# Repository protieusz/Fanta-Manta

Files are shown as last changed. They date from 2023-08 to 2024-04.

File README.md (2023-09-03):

# Fanta-Manta

Resurrection of the Manta closed source pcb by rainkeebs using Waveshare RP2040 zero.
Generously sponsored by jcastaneda from MechWild discord.

I did the design as closely to the originaly rainkeebs design as much as possible with the difference of using a RP2040 instead of Pro Micro.
This design resurrection was blessed by rainkeebs himself.
PCBs are currently in production. 1 Aug 2023.

Print the designs at your own risk.  No support is given. Thanks.

I accept any tips or donations of a cup of coffee to help keep me motivate but you don't have to if you don't want to. Thanks. https://ko-fi.com/protieusz
Update: 18 Aug 2023

Final Product Build






Unboxing


Front


Back


Test Fitting























PCB model

Front side




Bottom side. Fanta-Manta logo by jcastaneda


This logo is from https://logowik.com/fanta-new-vector-logo-3767.html


Case








Meme Add Case 3 Aug 2023










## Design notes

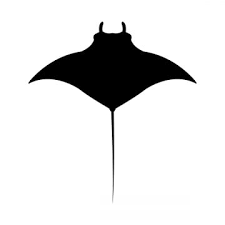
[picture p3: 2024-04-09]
STLs/Manta shape/Manta.png

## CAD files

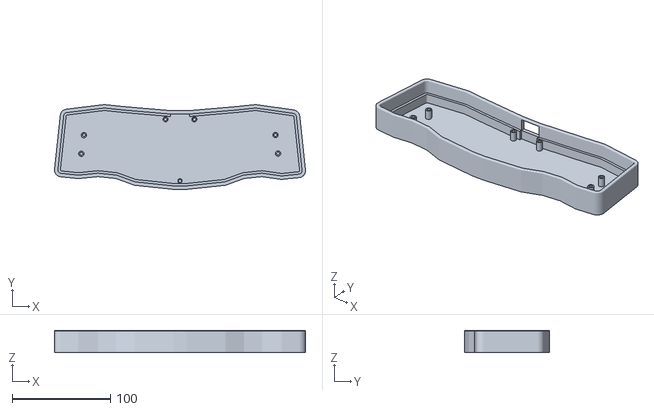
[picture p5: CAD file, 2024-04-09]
STLs/FullCase/FANTA MANTA FullCase.stl
255.0 x 86.1 x 22.8

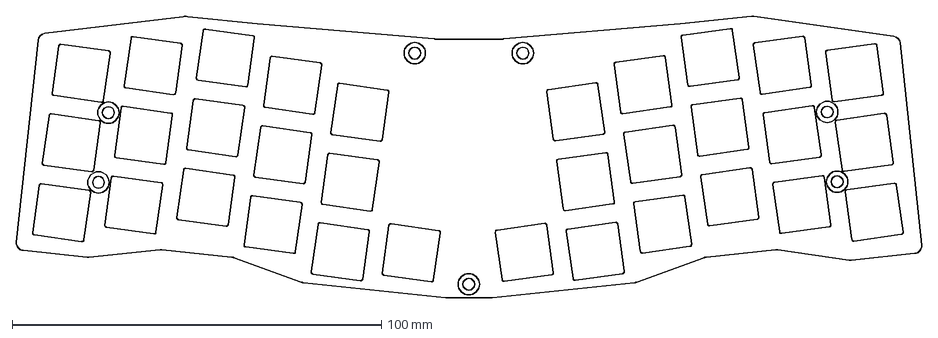
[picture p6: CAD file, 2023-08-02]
Correct Scale Fanta/FantaCorrectDxf.dxf
245.1 x 76.2 mm

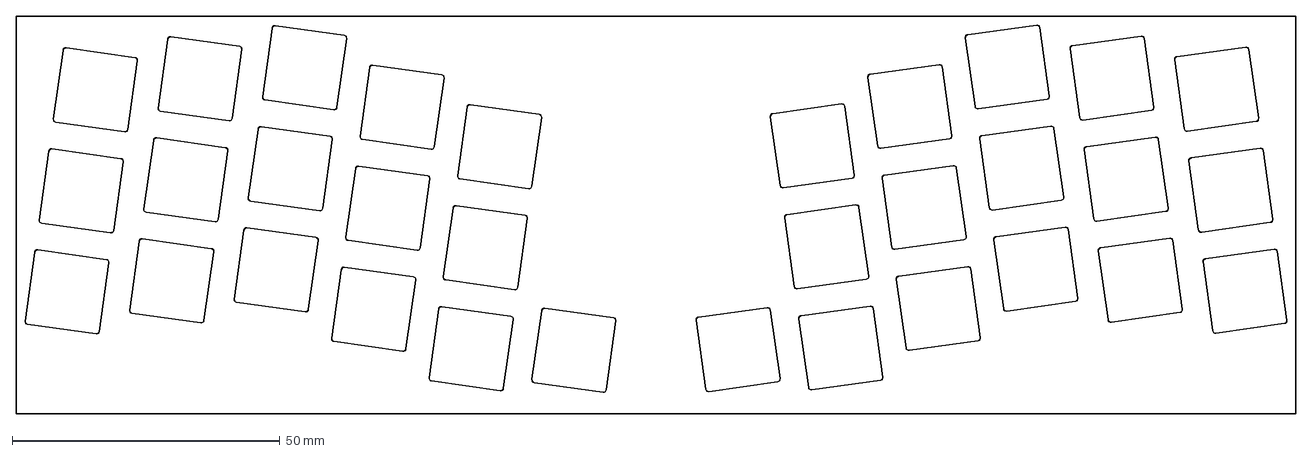
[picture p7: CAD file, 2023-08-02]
KLE layout/FantaKeylayout.dxf
239.0 x 74.3 mm

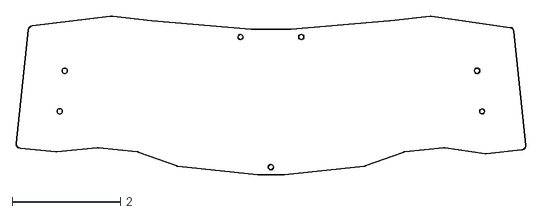
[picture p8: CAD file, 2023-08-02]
OriginNotToScalebottomplate/bottom_plate-Edge_Cuts.dxf
9.43 x 2.93

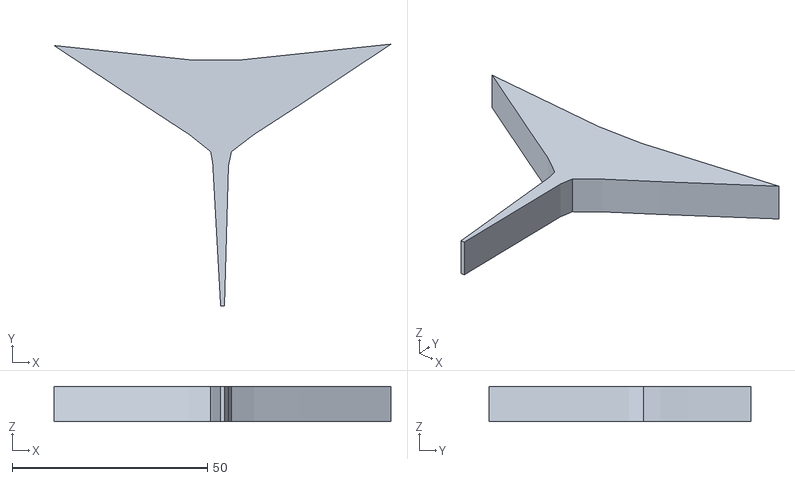
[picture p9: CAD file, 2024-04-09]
STLs/FANTA MANTATail.stl
86.3 x 67.1 x 9.00

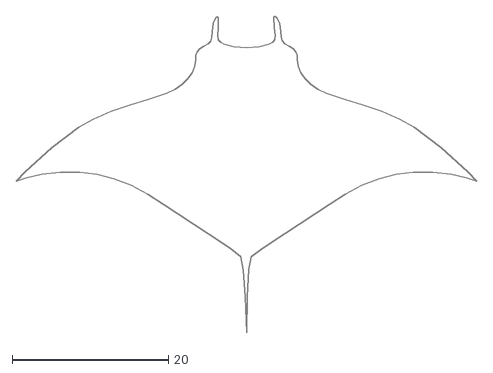
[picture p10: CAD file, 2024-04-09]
STLs/Manta shape/FabConvert.com_manta.dxf
59.0 x 40.5

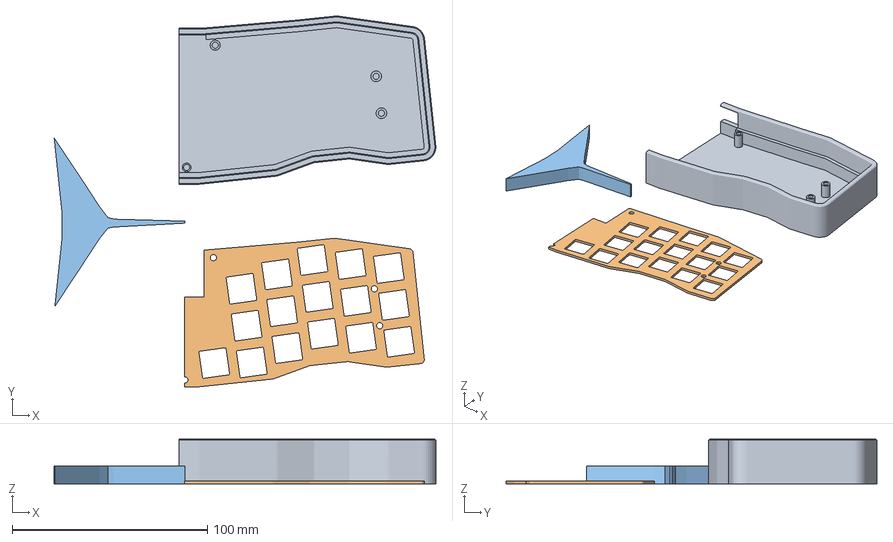
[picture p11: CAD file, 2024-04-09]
STLs/RPL/UM2_FANTA MANTACaseSWRIGHTTail.3mf
195.4 x 189.9 x 22.8 mm
FANTA MANTACaseRIGHT.stl
FANTA MANTASwitchRIGHT.stl
FANTA MANTATail.stl

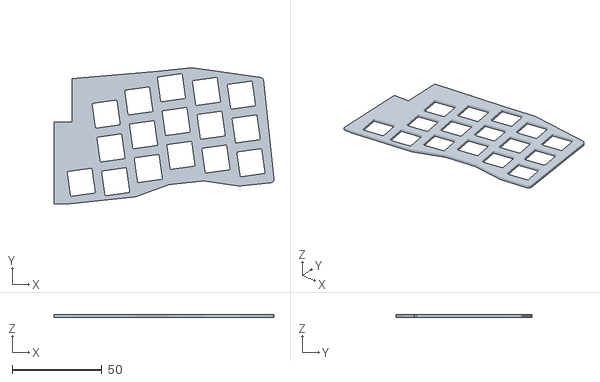
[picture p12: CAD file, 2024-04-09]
STLs/SplitCase/FANTA MANTASwitchRIGHT.stl
122.7 x 76.1 x 1.50

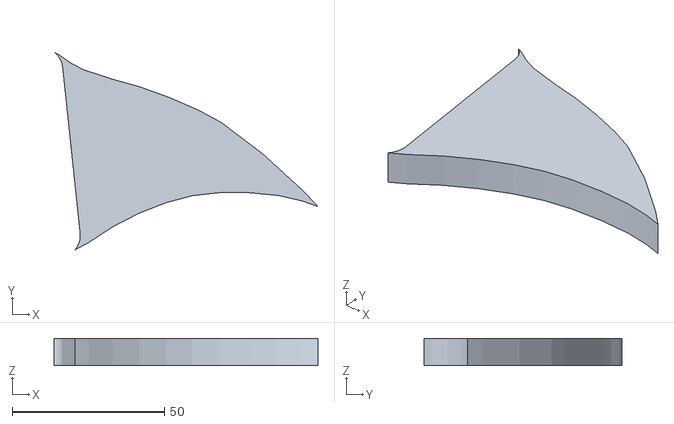
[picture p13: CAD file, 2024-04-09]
STLs/FANTA MANTARIGHTWing.stl
86.8 x 65.1 x 9.00

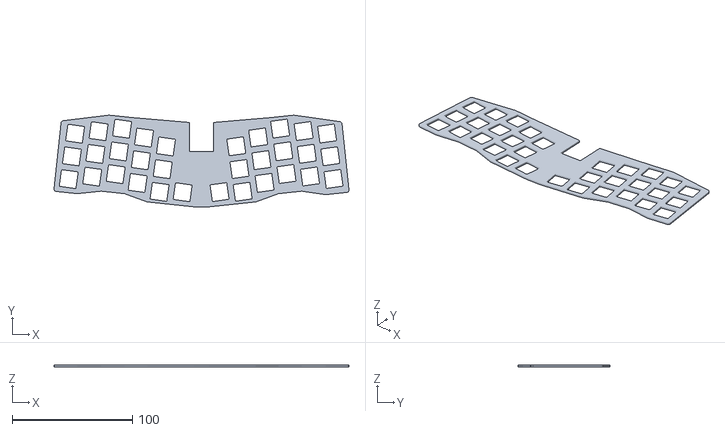
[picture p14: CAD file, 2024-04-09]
STLs/FullCase/FANTA MANTA SwitchPlateNoHoles.stl
245.0 x 76.1 x 1.50

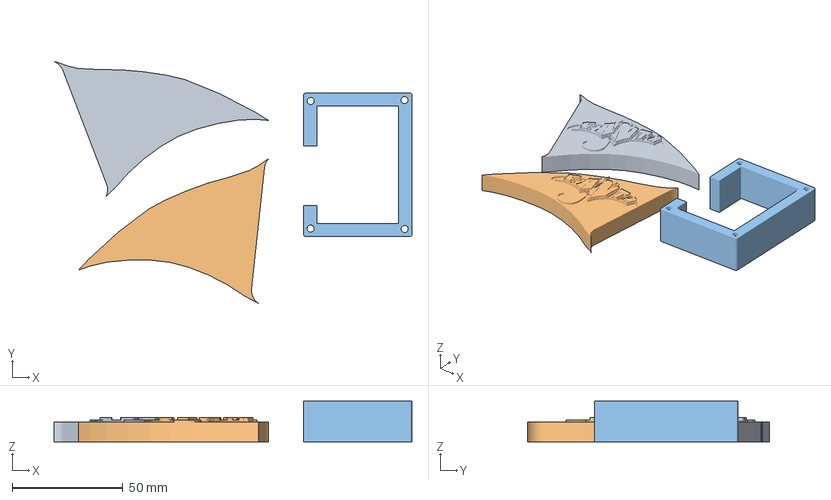
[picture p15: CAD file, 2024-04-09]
STLs/RPL/UM2_FANTA MANTARightLeftWingLogo.3mf
161.9 x 109.4 x 18.5 mm
FANTA MANTALeftWingLogo.stl
FANTA MANTARightWingLogo.stl
ScottoFlyTPS65SupportHoles.stl

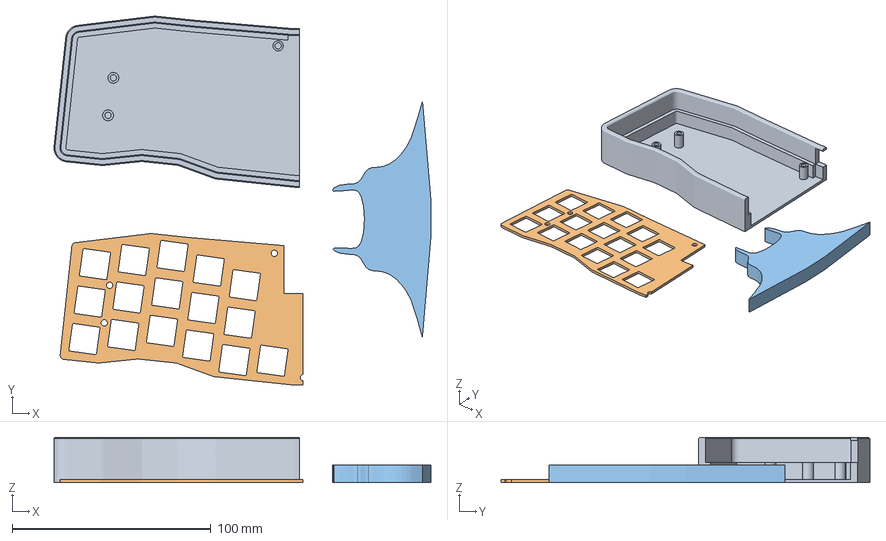
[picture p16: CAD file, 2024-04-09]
STLs/RPL/UM2_FANTA MANTACaseSWLEFTHead.3mf
189.8 x 185.6 x 22.8 mm
FANTA MANTACaseLEFT.stl
FANTA MANTASwitchLEFT.stl
FANTA MANTAHead.stl

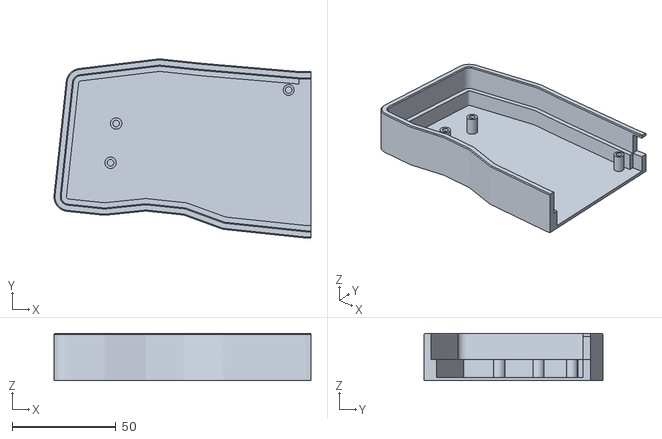
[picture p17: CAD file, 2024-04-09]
STLs/SplitCase/FANTA MANTACaseLEFT.stl
123.6 x 86.1 x 22.8

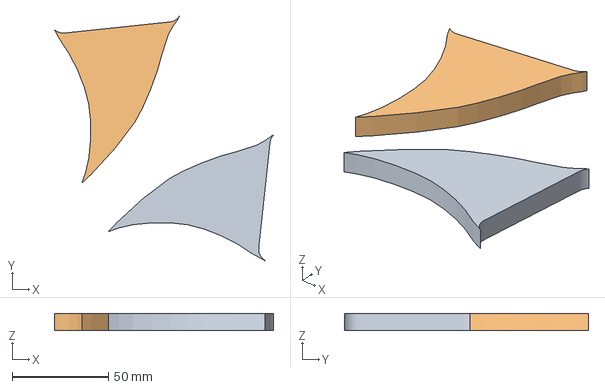
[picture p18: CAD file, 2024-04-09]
STLs/RPL/UM2_FANTA MANTALeftRightWing.3mf
114.2 x 127.1 x 9.00 mm
FANTA MANTALeftWing.stl
FANTA MANTARIGHTWing.stl

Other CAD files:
STLs/SplitCase/FANTA MANTASwitchLEFT.stl
STLs/FANTA MANTASwitchLEFT.stl
STLs/FANTA MANTACaseLEFT.stl
STLs/SplitCase/FANTA MANTACaseRIGHT.stl
STLs/FANTA MANTACaseRIGHT.stl
STLs/FANTA MANTAHead.stl
STLs/FANTA MANTALeftWing.stl
STLs/FANTA MANTALeftWingLogo.stl
STLs/FANTA MANTARightWingLogo.stl
STLs/FANTA MANTASwitchRIGHT.stl

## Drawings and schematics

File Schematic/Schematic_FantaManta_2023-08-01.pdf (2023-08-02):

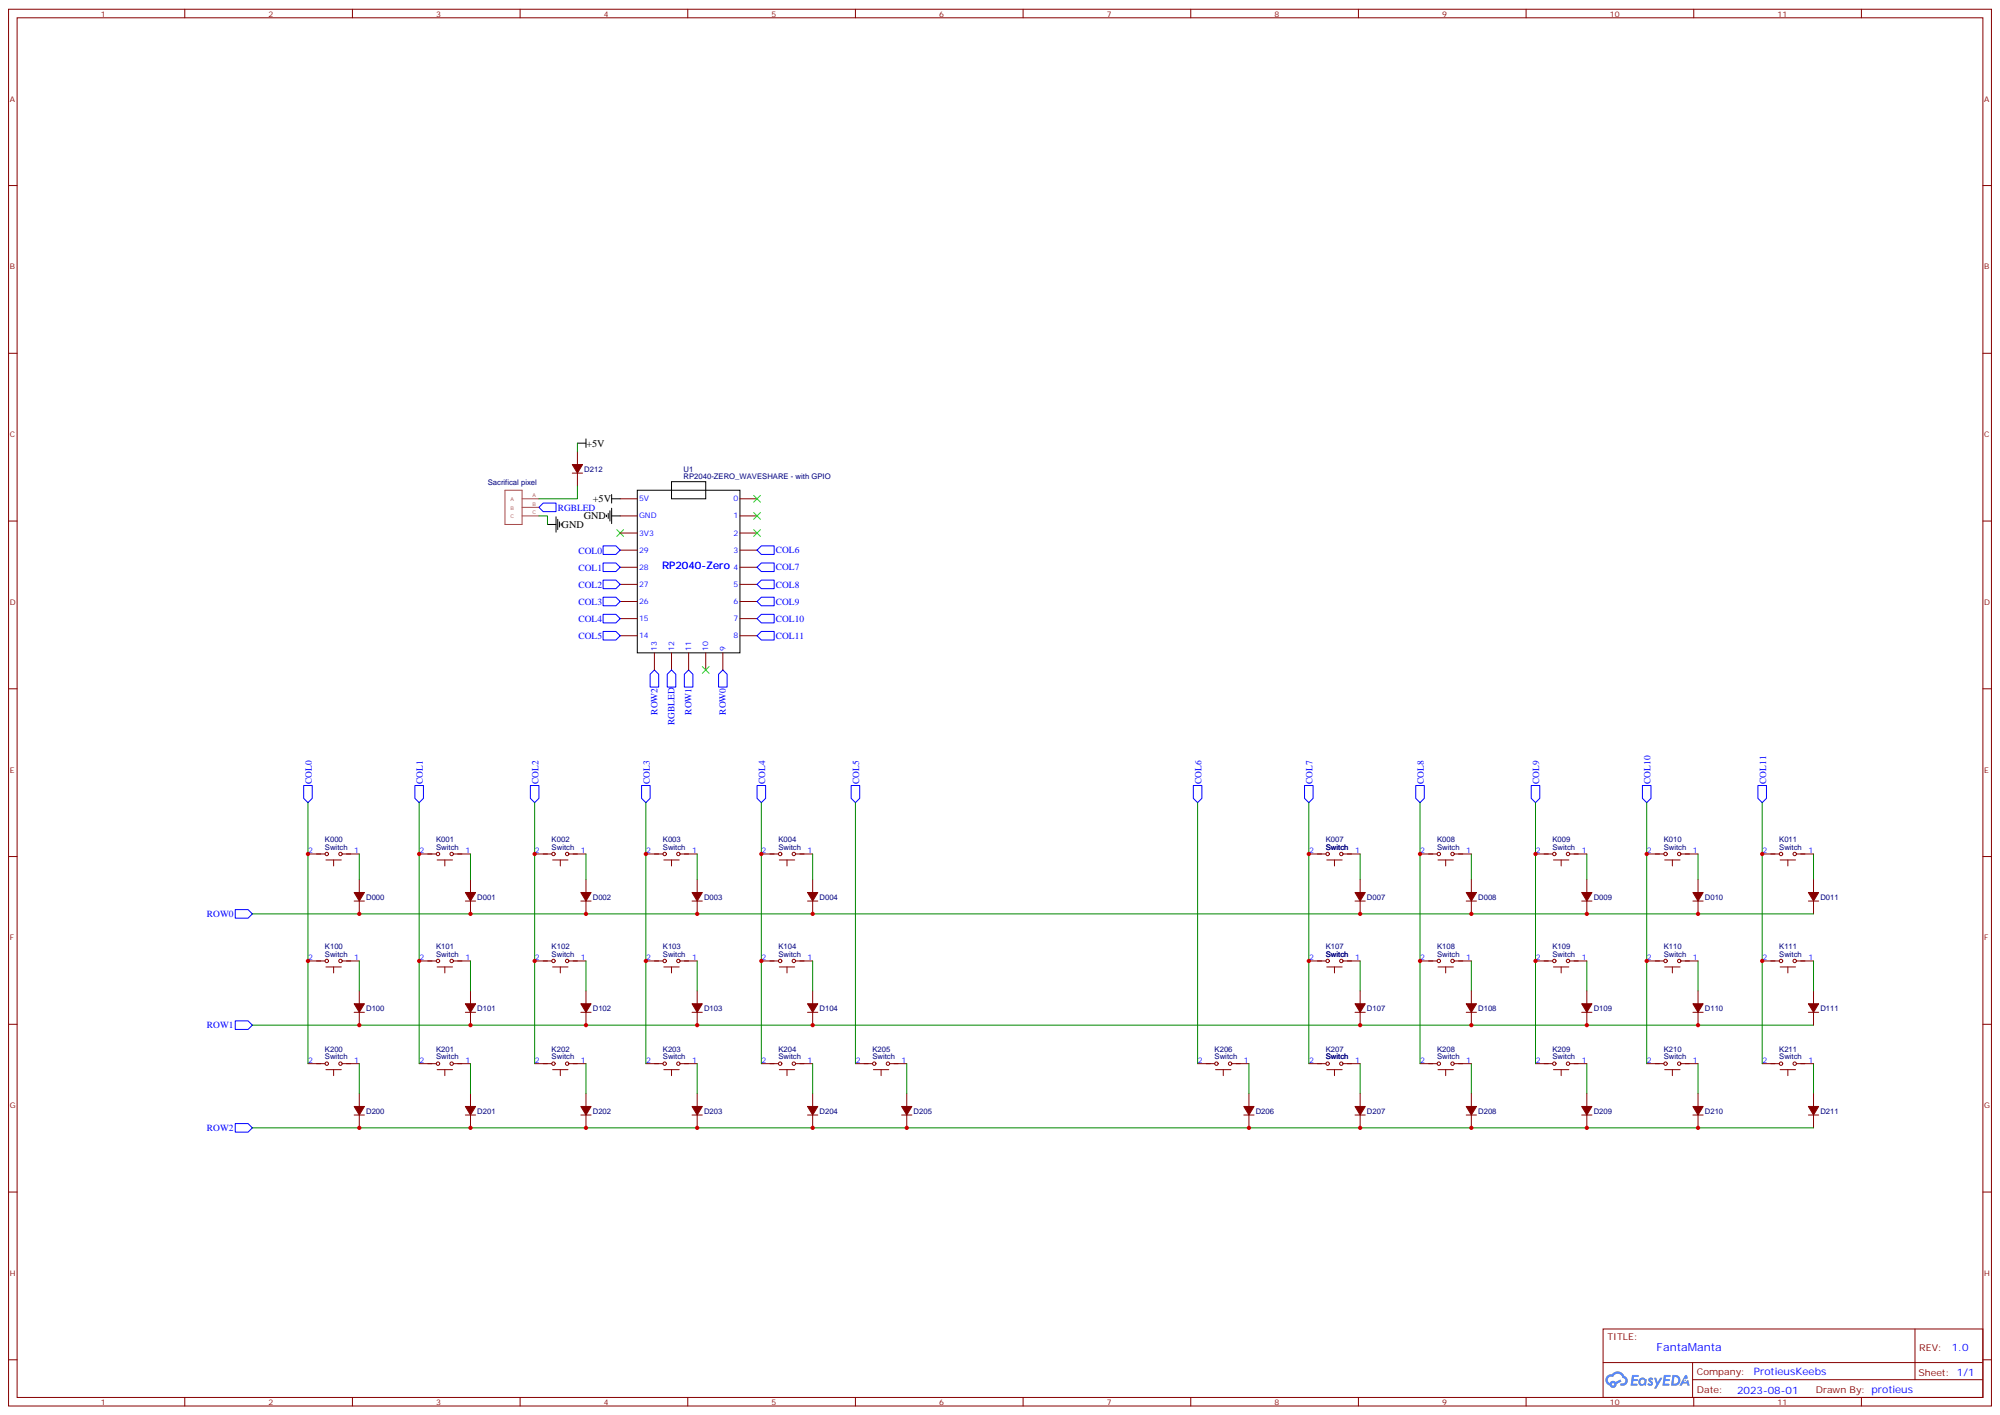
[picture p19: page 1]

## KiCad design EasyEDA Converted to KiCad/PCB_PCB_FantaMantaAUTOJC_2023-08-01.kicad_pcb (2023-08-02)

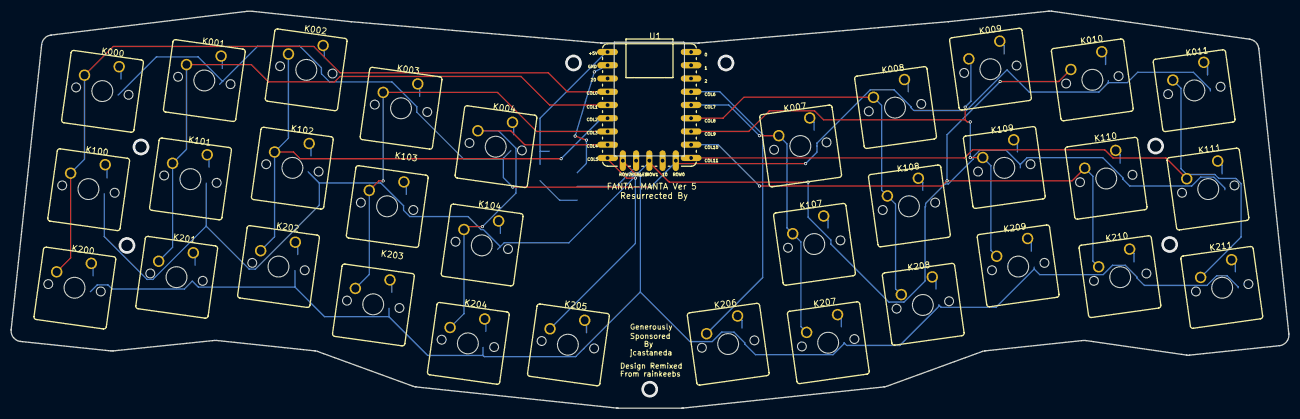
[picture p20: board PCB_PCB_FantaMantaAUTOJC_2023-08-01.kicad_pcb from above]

Board: 2 copper layers, 245.1 x 76.1 mm, 67 parts (0 on the bottom side), 51 nets.

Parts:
1: Sacrifical pixel; LEDSTRIP-3P
D000, D001, D002, D003, D004, D007, D008, D009, D010, D011, D100, D101, D102, D103, D104, D107, D108, D109, D110, D111, D200, D201, D202, D203, D204, D205, D206, D207, D208, D209, D210, D211, D212: SM4007PL; SOD-123F_L2.8-W1.8-LS3.7-RD
K000, K001, K002, K003, K004, K007, K008, K009, K010, K011, K100, K101, K102, K103, K104, K107, K108, K109, K110, K111, K200, K201, K202, K203, K204, K205, K206, K207, K208, K209, K210, K211: 100; CHERRY_MX_100_MILLMAX
U1: RP2040-ZERO_WAVESHARE - with GPIO; RP2040-ZERO_WAVESHARE- W/ GPIO

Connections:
1_A: 1.A, D212.1
+5V: D212.2, U1.22
COL0: K000.2, K100.2, K200.2, U1.19
COL1: K001.2, K101.2, K201.2, U1.18
COL2: K002.2, K102.2, K202.2, U1.17
COL3: K003.2, K103.2, K203.2, U1.16
COL4: K004.2, K104.2, K204.2, U1.15
COL5: K205.2, U1.14
COL6: K206.2, U1.3
COL7: K007.2, K107.2, K207.2, U1.4
COL8: K008.2, K108.2, K208.2, U1.5
COL9: K009.2, K109.2, K209.2, U1.6
COL10: K010.2, K110.2, K210.2, U1.7
COL11: K011.2, K111.2, K211.2, U1.8
D111_2: D111.2, K111.1
D205_2: D205.2, K205.1
D206_2: D206.2, K206.1
GND: 1.C, U1.21
K000_1: D000.2, K000.1
K001_1: D001.2, K001.1
K002_1: D002.2, K002.1
K003_1: D003.2, K003.1
K004_1: D004.2, K004.1
K007_1: D007.2, K007.1
K008_1: D008.2, K008.1
K009_1: D009.2, K009.1
K010_1: D010.2, K010.1
K011_1: D011.2, K011.1
K100_1: D100.2, K100.1
K101_1: D101.2, K101.1
K102_1: D102.2, K102.1
K103_1: D103.2, K103.1
K104_1: D104.2, K104.1
K107_1: D107.2, K107.1
K108_1: D108.2, K108.1
K109_1: D109.2, K109.1
K110_1: D110.2, K110.1
K200_1: D200.2, K200.1
K201_1: D201.2, K201.1
K202_1: D202.2, K202.1
K203_1: D203.2, K203.1
K204_1: D204.2, K204.1
K207_1: D207.2, K207.1
K208_1: D208.2, K208.1
K209_1: D209.2, K209.1
K210_1: D210.2, K210.1
K211_1: D211.2, K211.1
RGBLED: 1.B, U1.12
ROW0: D000.1, D001.1, D002.1, D003.1, D004.1, D007.1, D008.1, D009.1, D010.1, D011.1, U1.9
ROW1: D100.1, D101.1, D102.1, D103.1, D104.1, D107.1, D108.1, D109.1, D110.1, D111.1, U1.11
ROW2: D200.1, D201.1, D202.1, D203.1, D204.1, D205.1, D206.1, D207.1, D208.1, D209.1, D210.1, D211.1, U1.13

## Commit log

2023-08-02 Original dxf from rainkeebs
    Not to scale.
    [bottom_plate-Edge_Cuts.dxf]
2023-08-02 KLE layout only
    [FantaKeylayout.dxf]
2023-08-02 Correct scale of FantaManta
    [FantaCorrectDxf.dxf]
2023-08-02 Gerber files
2023-08-02 Converted pcb to KiCad
    Not perfect
    [PCB_PCB_FantaMantaAUTOJC_2023-08-01.kicad_pcb]
2023-08-03 Update README.md
    Add meme case add on
2023-08-03 Update README.md
    Add case model
2024-04-09 STL Case Files
    [FANTA MANTA FullCase.stl, FANTA MANTA SwitchPlateNoHoles.stl, FANTA MANTACaseLEFT.stl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]
